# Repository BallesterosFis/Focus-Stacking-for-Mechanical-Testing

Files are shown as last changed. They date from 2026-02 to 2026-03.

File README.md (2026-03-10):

# Robotic Microscopy open-source setups for all in focus computational imaging at low cost

## Abstract

This repository contains the hardware control scripts and computational tools supporting the robotic focus stacking system.

The system addresses depth of field limitations in optical microscopy during tribological and mechanical surface analysis. By integrating a motorized Z-axis stage with automated image acquisition and post-processing, the setup enables reproducible extended depth-of-field (EDOF) imaging using a low-cost optical platform.

---

## Scientific Motivation

Extended depth of field (EDOF) imaging mitigates the limitations of conventional optical microscopy by computationally merging multiple focal planes into a single fully focused image. However, commercial automated systems remain costly and frequently closed-source.

This project implements a fully reproducible robotic focus stacking workflow based on:

- Motorized Z-axis control  
- Theoretical depth of field estimation  
- Automated stack acquisition  
- Alignment and EDOF reconstruction  
- Optional 3D surface visualization  

---

## System Architecture

The complete workflow is structured as follows:

Optical Setup  
↓  
Experimental DOF Estimation (`DOF.py`)  
↓  
Motorized Z-Stack Acquisition (`z_stack_capture.py`)  
↓  
Stack Alignment (SIFT-based registration in Fiji)  
↓  
Extended Depth of Field Reconstruction  
↓  
3D Surface Visualization  

The hardware implementation is based on an OpenFlexure microscope platform integrated with a motorized Z-stage controlled by a Raspberry Pi.

---

## Repository Structure

- `z_stack_capture.py`  
  Controls Z-axis motion and automated image acquisition via Raspberry Pi and Sangaboard.

- `DOF.py`  
  Calculates the experimental depth of field based on three metrics (Laplacian variance, Tenengrad gradient, and wavelet energy) and the 80% and FWHM creteria.

- `BOM.md`  
  Bill of materials including hardware components and cost estimation (~300 USD total system cost).

## Experimental Results

The system enables:

- Fully focused composite images of wear tracks and surface defects  
- Improved visualization of depth-dependent features  
- 3D surface rendering from focal stacks  

---

## Reproducibility

All scripts are designed to run on a Raspberry Pi (Python 3.7+) with standard scientific libraries:

- numpy  
- opencv-python  
- RPi.GPIO  
- picamera  

Post-processing is performed using Fiji (ImageJ) with:

- [Linear Stack Alignment with SIFT ](https://imagej.net/plugins/linear-stack-alignment-with-sift) 
- [Extended Depth of Field (Expert Mode) ](https://imagej.net/plugins/extended-depth-of-field) 
- [3D Surface Plot ](https://imagej.net/ij/plugins/surface-plot-3d.html) 

---

## Limitations

Current implementation:

- Requires post-processing in Fiji (not fully integrated in Python)  
- Assumes stable illumination and minimal lateral drift   

Future work will focus on full pipeline automation and improved illumination stability control.

## License

CERN Open Hardware Licence v1.2

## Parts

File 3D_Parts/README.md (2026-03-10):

# 3D Parts

This directory contains all the necessary files for 3D printing the microscope parts. Our assembly is based on the **OpenFlexure Delta Stage** design.

## About the "modified" files

When reviewing the file list, you will notice that some files end with the word **"modified"**. 

These are **custom modifications** we had to make to the original design. They were created to correct certain geometric design errors or to update parts that presented compatibility issues in the original files. 

> **Note:** We highly recommend using these "modified" versions for printing to ensure the mechanism works correctly without the issues identified in the base version.

## Assembly Instructions and Base Files

The original files this project is based on, as well as the detailed step-by-step guide to assemble the microscope, can be found in the official OpenFlexure documentation. 

You can check the assembly steps and view the original files here:
**[OpenFlexure Delta Stage v1.2.2](https://build.openflexure.org/openflexure-delta-stage/v1.2.2/)**

Please follow the instructions in that link for the physical assembly, simply replacing the original parts with our "modified" versions where applicable.

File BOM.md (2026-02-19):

# Bill of Materials (BOM)

This document lists all components required to build the automated Focus Stacking microscope (OpenFlexure microscope).

**Estimated Grand Total:** $291.50 USD

## 1. Optics
| Component | Specification | Quantity | Approx. Cost (USD) | Supplier|
| :--- | :--- | :--- | :--- | :--- |
| Objective Lens | 20x Plan Achromatic (RMS, NA 0.40) | 1 | $83.00 | [20X microscope infinite plane long working distance objective](https://es.aliexpress.com/item/1005003369305362.html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)
| Tube Lens | Achromatic doublet ($f=50mm$) | 1 | $25.00 | [Io Rodeo Achromatic lens](https://iorodeo.com/products/achromatic-lens)
| Camera | Raspberry Pi Camera 8MP | 1 | $30.00 | [Raspberry Pi Camera Module V2](https://www.amazon.com/-/es/dp/B01ER2SKFS?ref=ppx_yo2ov_dt_b_fed_asin_title&language=en_US)
| Condenser Lens | PMMA lens $5mm \times 13mm$ | 1 | $0.50 | [Condenser Lens ](https://es.aliexpress.com/item/1052713746.html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)
| Light Source | Star LED | 1 | $1.00 | [White LED](https://www.sigmaelectronica.net/producto/led-3w-blanco/)
| Beamsplitter | $12 mm \times 18 mm$ | 1 | $2.00 | [Beamsplitter](https://es.aliexpress.com/item/1005007473867436.html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)

## 2. Motion Control & Electronics
| Component | Specification | Quantity | Approx. Cost (USD) | Supplier|
| :--- | :--- | :--- | :--- | :--- |
| Motors | 28BYJ-48 Stepper Motors (5V) | 3 | $12.00 | [Stepper Motors](https://electronilab.co/tienda/motor-paso-a-paso-28byj-48-0-3kgr-cm/) 
| Motor Driver | Sangaboard | 1 | $35.00 | [Sangaboard](https://iorodeo.com/products/sangaboard-v0-5)
| Computer | Raspberry Pi 4 Model B (4 GB RAM) | 1 | $55.00 | [Raspberry Pi 4](https://www.amazon.com/-/es/dp/B07TC2BK1X?ref=ppx_yo2ov_dt_b_fed_asin_title)
| Storage | microSDXC UHS-I Extreme 64 GB | 1 | $15.00 | [Micro SD 64 GB](https://www.amazon.com/-/es/SanDisk-Tarjeta-microSDXC-adaptador-SDSQXAH-064G-GN6MA/dp/B09X7C7LL1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)
| Power | Raspberry Pi Power Supply | 1 | $5.00 | [Power Supply](https://iorodeo.com/products/raspberry-pi-power-supply)

## 3. Mechanics & Hardware
| Component | Specification | Quantity | Approx. Cost (USD) | Supplier|
| :--- | :--- | :--- | :--- | :--- |
| O-Rings | Nitrile, OD: 34mm | 3 | $1.50 | [O-Rings](https://es.aliexpress.com/item/1005006417147355.html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)
| Screws M2 | M2 x 6mm | 2 | $0.50 |-
| Nuts/Washers M2.5 | Nut M2.5, Washer M2.5, Screw M2.5 x 8mm | Set | ~$4.00 | -
| Screws M3 | M3 (6mm, 8mm, 12mm, 25mm), Nuts, Washers | Set | ~$6.50 | -
| Screws M4 | M4 x 6mm | 6 | $1.00 | -

## 4. 3D Printed Parts
All STL files are available in the `/3D_Parts/` directory of this repository.

---

### 4.1 Recommended Printing Parameters

- **Material:** PLA  
- **Layer height:** 0.2 mm  
- **Infill:** 20–30% (rectilinear or grid pattern)  
- **Nozzle diameter:** 0.4 mm  
- **Supports:** Not required for any part  

---

### 4.2 Printed Components 

* 1x [Main Body](https://github.com/BallesterosFis/Focus-Stacking-for-Mechanical-Testing/blob/main/3D_Parts/Main_Body.stl)
* 1x [Raspberry Pi & Sangaboard Base](https://github.com/BallesterosFis/Focus-Stacking-for-Mechanical-Testing/blob/main/3D_Parts/Illumination_Condenser%20(Modified).stl)
* 1x [Reflection Illumination Condenser](https://github.com/BallesterosFis/Focus-Stacking-for-Mechanical-Testing/blob/main/3D_Parts/Illumination_Condenser%20(Modified).stl)
* 1x [Reflection Illumination Holder](https://github.com/BallesterosFis/Focus-Stacking-for-Mechanical-Testing/blob/main/3D_Parts/Illumination_Holder.stl)
* 1x [Reflection Optics Module Casing](https://github.com/BallesterosFis/Focus-Stacking-for-Mechanical-Testing/blob/main/3D_Parts/optics_picamera2_rms_f50d13_beamsplitter_delta.stl)
* 1x [Camera Cover](https://github.com/BallesterosFis/Focus-Stacking-for-Mechanical-Testing/blob/main/3D_Parts/picamera_2_cover.stl)
* 1x [Filter Cube](https://github.com/BallesterosFis/Focus-Stacking-for-Mechanical-Testing/blob/main/3D_Parts/Filter_Cube.stl)
* 3x [Large Gear](https://github.com/BallesterosFis/Focus-Stacking-for-Mechanical-Testing/blob/main/3D_Parts/large_gears.stl)
* 3x [Small Gear](https://github.com/BallesterosFis/Focus-Stacking-for-Mechanical-Testing/blob/main/3D_Parts/small_gears.stl)
* 2x [Sample Clip](https://github.com/BallesterosFis/Focus-Stacking-for-Mechanical-Testing/blob/main/3D_Parts/sample_clips.stl)
* 3x [Feet](https://github.com/BallesterosFis/Focus-Stacking-for-Mechanical-Testing/blob/main/3D_Parts/feet.stl)
* Tools: [Lens Tool](https://github.com/BallesterosFis/Focus-Stacking-for-Mechanical-Testing/blob/main/3D_Parts/lens_tool.stl), [Nut Tool, Band Tool](https://github.com/BallesterosFis/Focus-Stacking-for-Mechanical-Testing/blob/main/3D_Parts/actuator_assembly_tools.stl)

**Estimated 3D Printing Cost:** ~$15.00 (Filament cost)

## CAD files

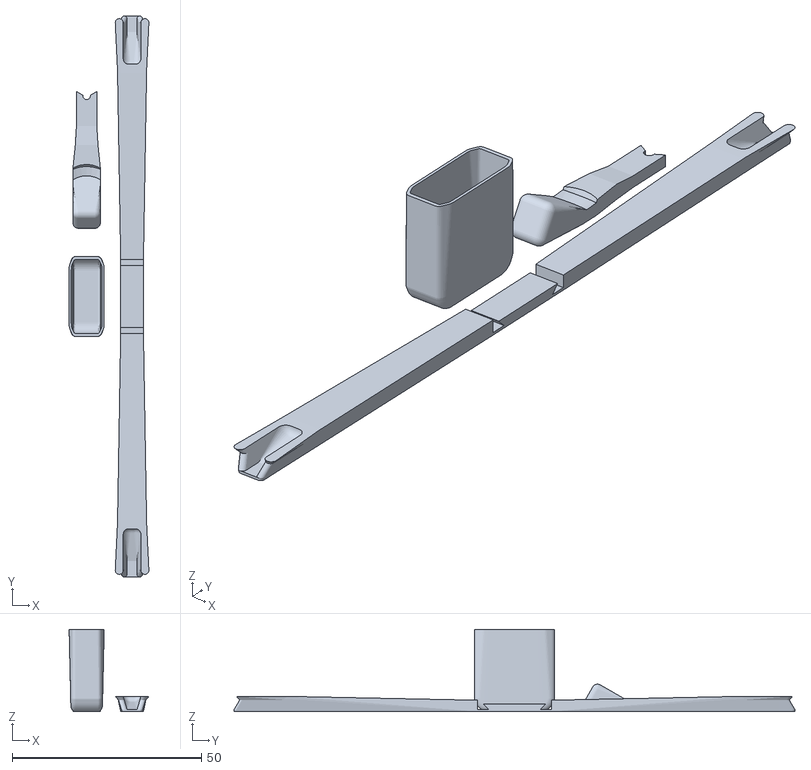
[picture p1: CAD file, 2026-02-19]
3D_Parts/actuator_assembly_tools.stl
21.1 x 148.2 x 21.7

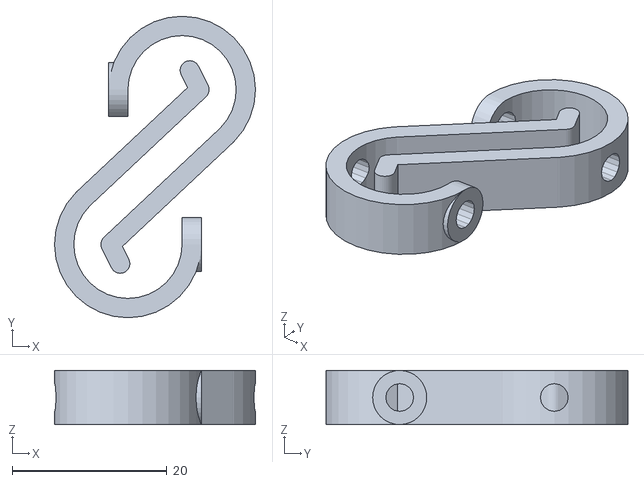
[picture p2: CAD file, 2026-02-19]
3D_Parts/sample_clips.stl
26.0 x 39.0 x 7.00

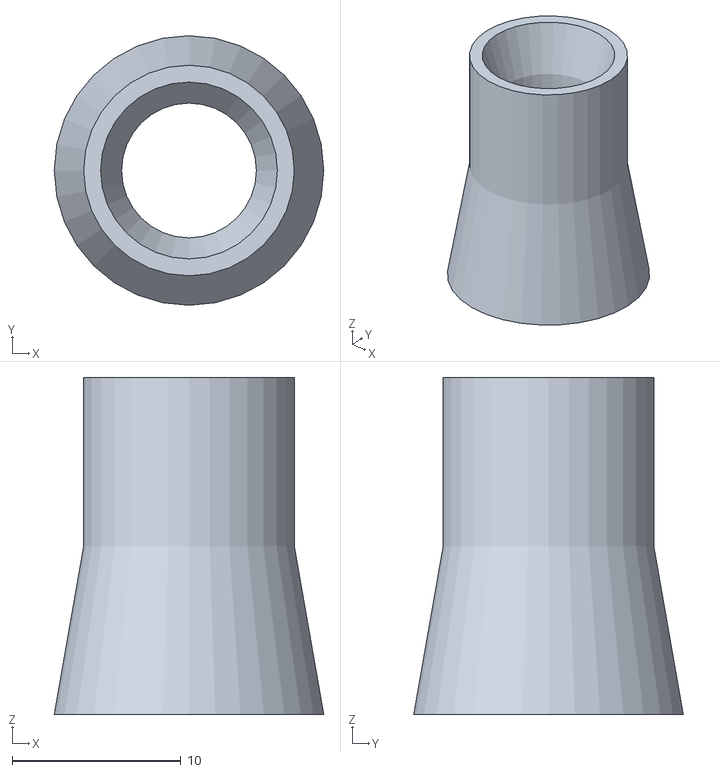
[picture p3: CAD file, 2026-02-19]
3D_Parts/lens_tool.stl
16.0 x 16.0 x 20.0

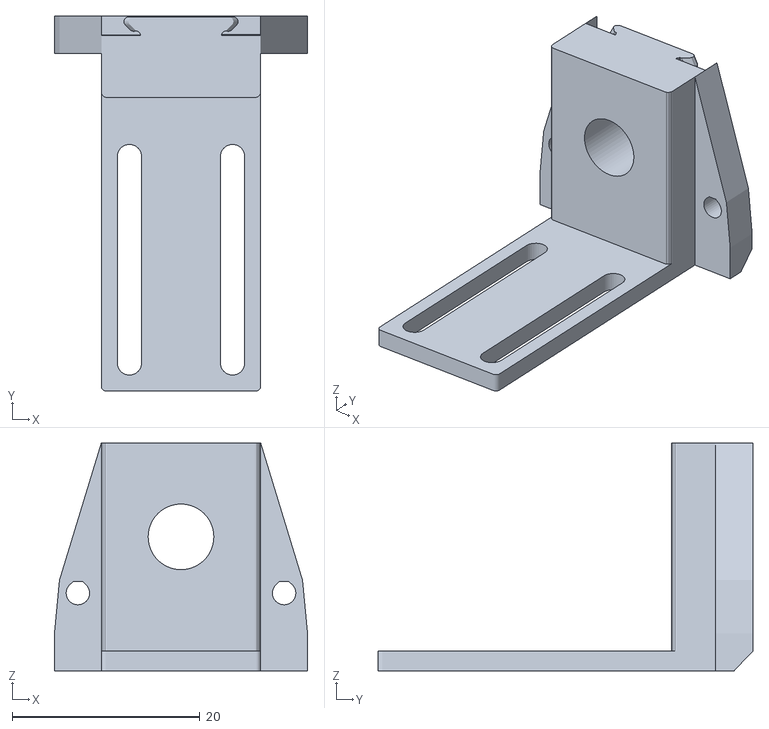
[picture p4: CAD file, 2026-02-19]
3D_Parts/Illumination_Holder.stl
27.0 x 40.0 x 24.3

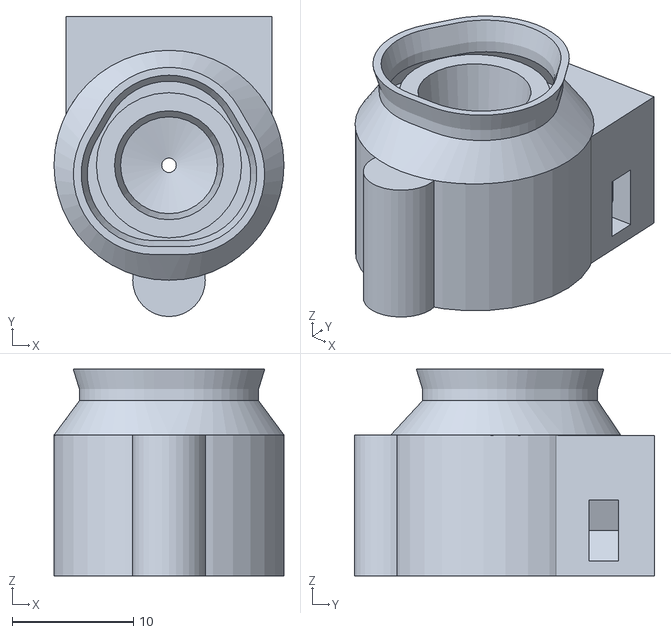
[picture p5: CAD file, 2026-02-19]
3D_Parts/Illumination_Condenser (Modified).stl
19.0 x 24.8 x 17.1

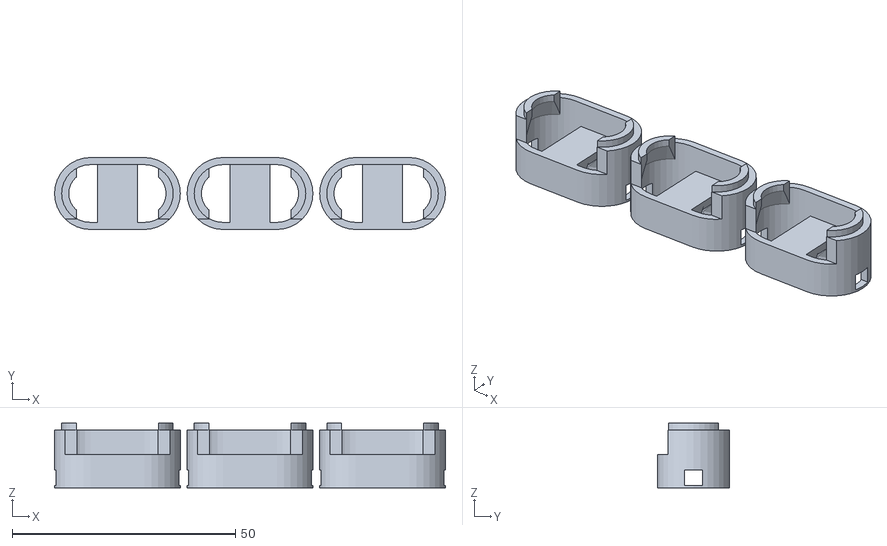
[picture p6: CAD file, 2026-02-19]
3D_Parts/feet.stl
87.6 x 16.1 x 14.5

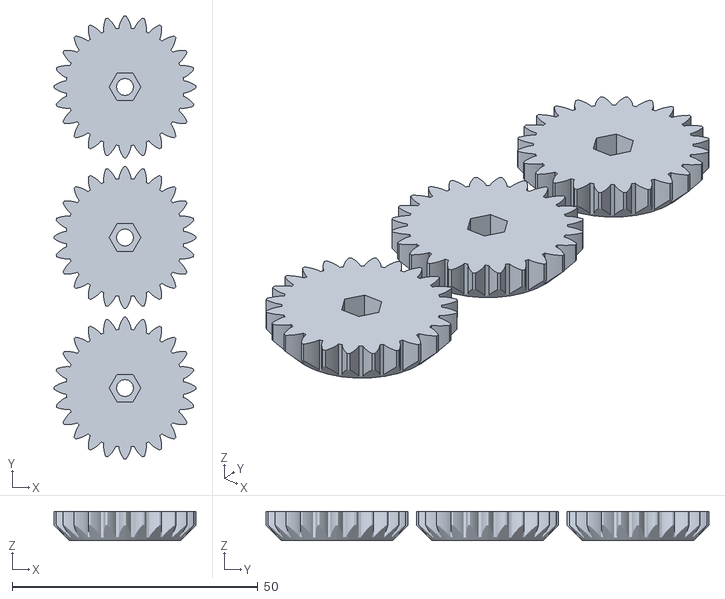
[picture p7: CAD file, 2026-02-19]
3D_Parts/large_gears.stl
28.9 x 90.2 x 6.00

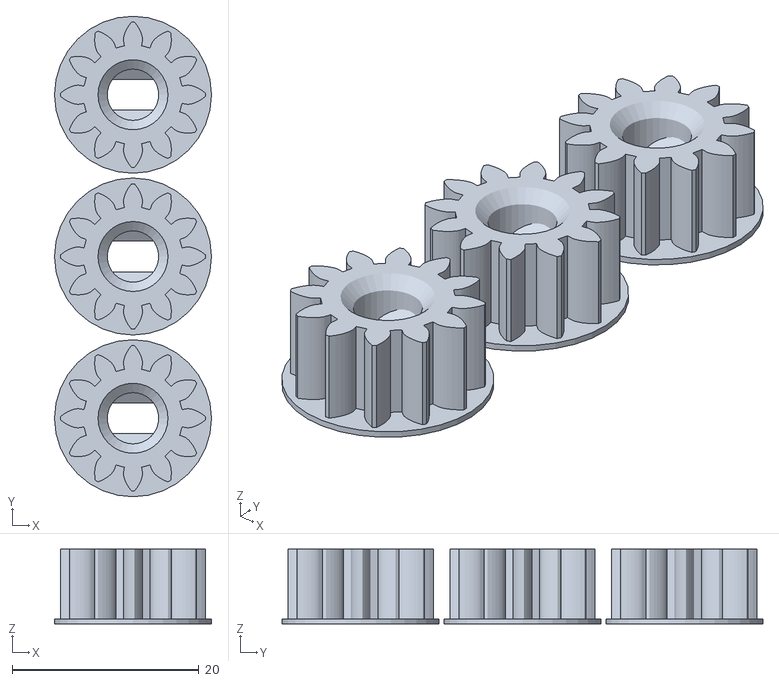
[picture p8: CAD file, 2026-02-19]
3D_Parts/small_gears.stl
16.8 x 51.5 x 8.00

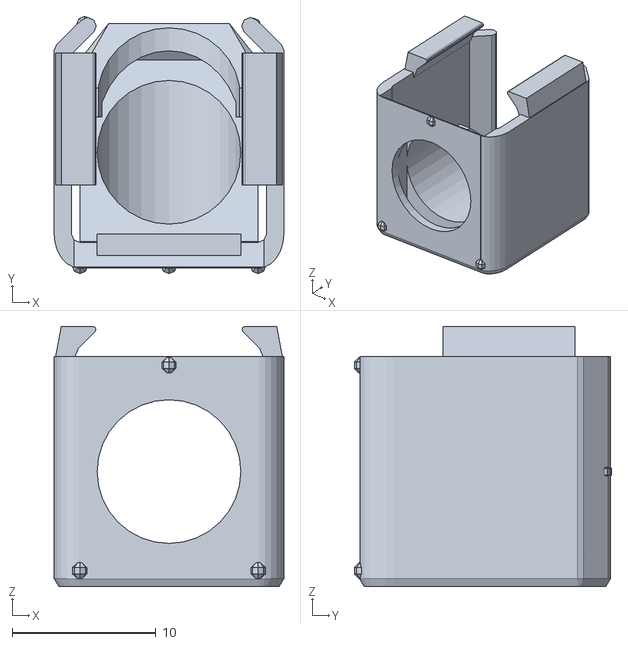
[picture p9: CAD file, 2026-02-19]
3D_Parts/Filter_Cube.stl
16.0 x 17.9 x 18.1

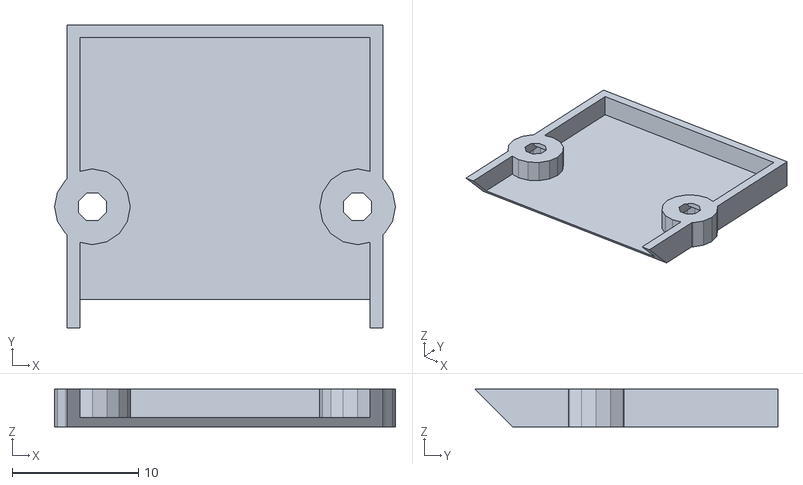
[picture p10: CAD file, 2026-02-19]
3D_Parts/picamera_2_cover.stl
27.0 x 24.0 x 3.00

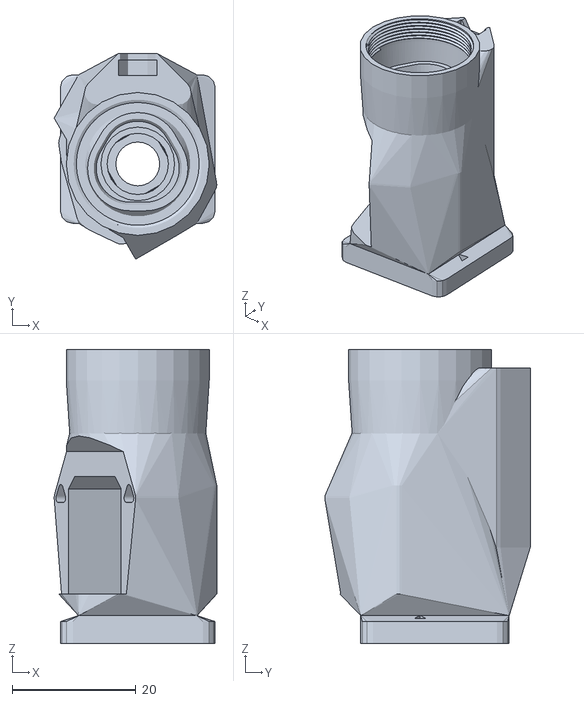
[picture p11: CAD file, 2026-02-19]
3D_Parts/Reflection_Optics_Module_Casing.stl
26.3 x 33.2 x 47.5

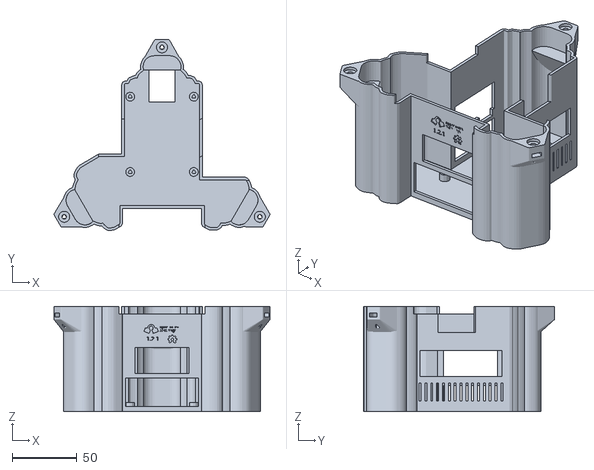
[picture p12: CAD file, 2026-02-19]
3D_Parts/base_raspi_sangaboard (Modified).stl
166.3 x 147.0 x 81.0

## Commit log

2026-02-12 Add Bill of Materials for Focus Stacking Microscope
    This document provides a detailed list of components required for building an automated Focus Stacking microscope, including estimated costs.
2026-02-12 Update BOM to include 3D printed feet
    Added 3x Feet to the list of 3D printed parts and updated BOM.
2026-02-12 Clarify microscope model and material recommendation
    Updated the BOM to specify the microscope model and material recommendation.
2026-02-12 Revise overview to mention tribological samples
    Updated project description to specify tribological samples.
2026-02-19 Raspberry Pi & Sangaboard Base (Modified)
    [base_raspi_sangaboard (USB C Space).stl]
2026-02-19 Add Filter_Cube.stl file
    [Filter_Cube.stl]
2026-02-19 Rename delta_stage_microscope_smart_brim.stl to Main Body.stl
    [Main Body.stl]
2026-02-19 Add links to 3D printed parts in BOM
    Updated 3D printed parts list with links to STL files.
2026-02-19 Update BOM with printing parameters and STL file info
    Added recommended printing parameters and updated STL file location.
2026-03-10 Create README.md for 3D parts directory
    Added README.md with information about 3D printing parts and assembly instructions.
